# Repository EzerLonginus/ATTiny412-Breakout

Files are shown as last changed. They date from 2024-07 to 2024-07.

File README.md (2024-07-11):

# ATTiny412-Breakout
Simple breakout for the ATTiny412 using USB for uploading and serial comms

This board is a simple breakout for the ATTiny412.  This allows for programming and UART serial communications through a USB interface.  Included in breakout is a power led indication, and a few feedback LEDs for UART and UPDI programming.  UPDI and UART need to be selected via switch on the front of the breakout.

## Purpose
I wanted a way to quickly and easily test some software with the attiny412 (or similar avr chip), and not have to have a programmer and separate power source connected to chip.  This usually involved using a USB connector for power (sometimes doubling as a serial comms port) and some UPDI programmer to upload code.  This board will hopefully just allow me to use the USB for all functionality and to make development a little be cleaner and easier. 

## Scematic
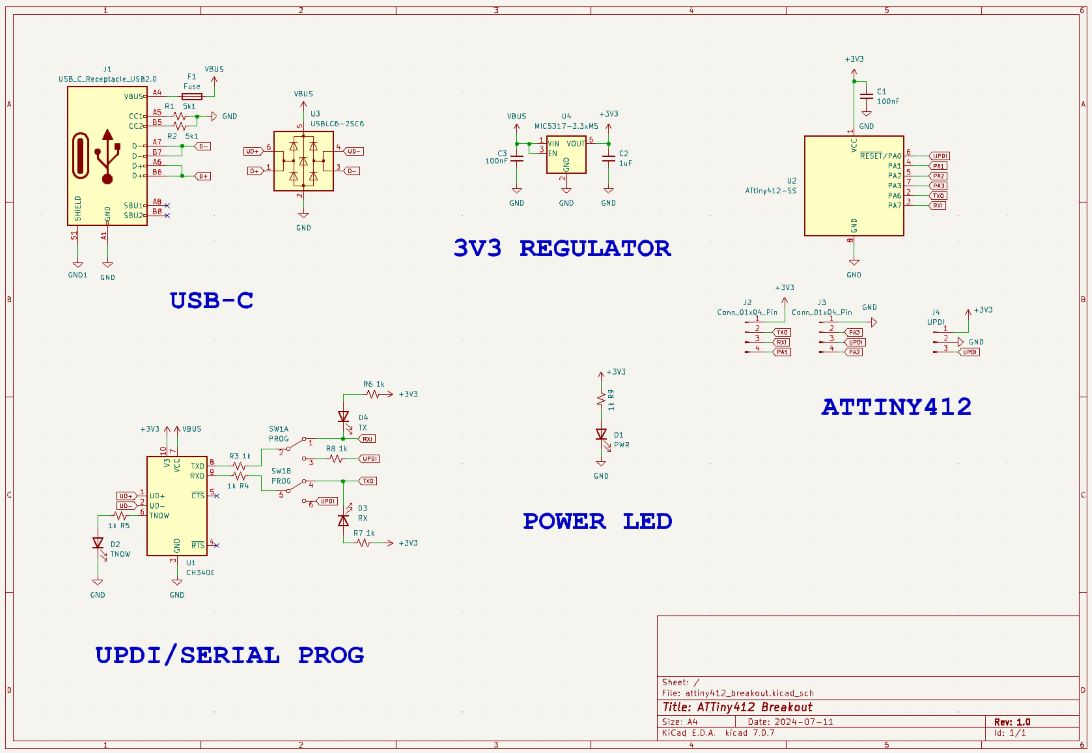
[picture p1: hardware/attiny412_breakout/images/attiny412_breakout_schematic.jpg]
ATTiny412 Schematic


## Layout
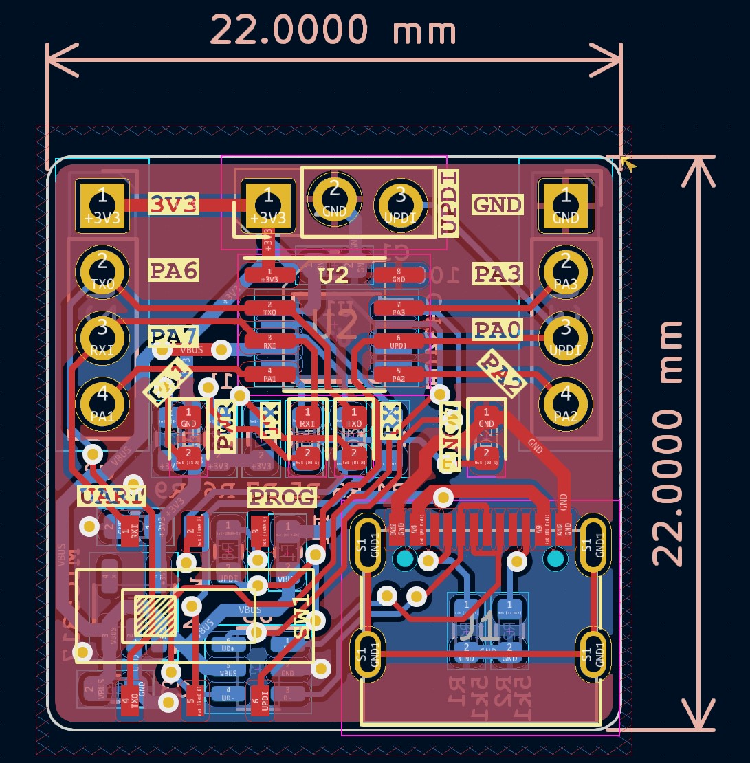
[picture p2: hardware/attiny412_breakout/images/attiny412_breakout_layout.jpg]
ATTiny412 Layout


## 3D Render
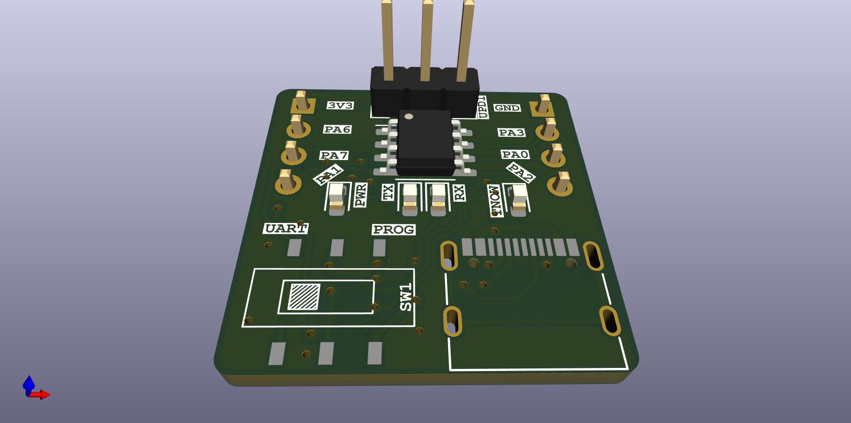
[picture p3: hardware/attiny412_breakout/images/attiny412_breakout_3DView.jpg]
ATTiny412 Render


## Current State of Affairs
### Version 1
* Populate and test board
* Fix the inevitable issue that I missed during production

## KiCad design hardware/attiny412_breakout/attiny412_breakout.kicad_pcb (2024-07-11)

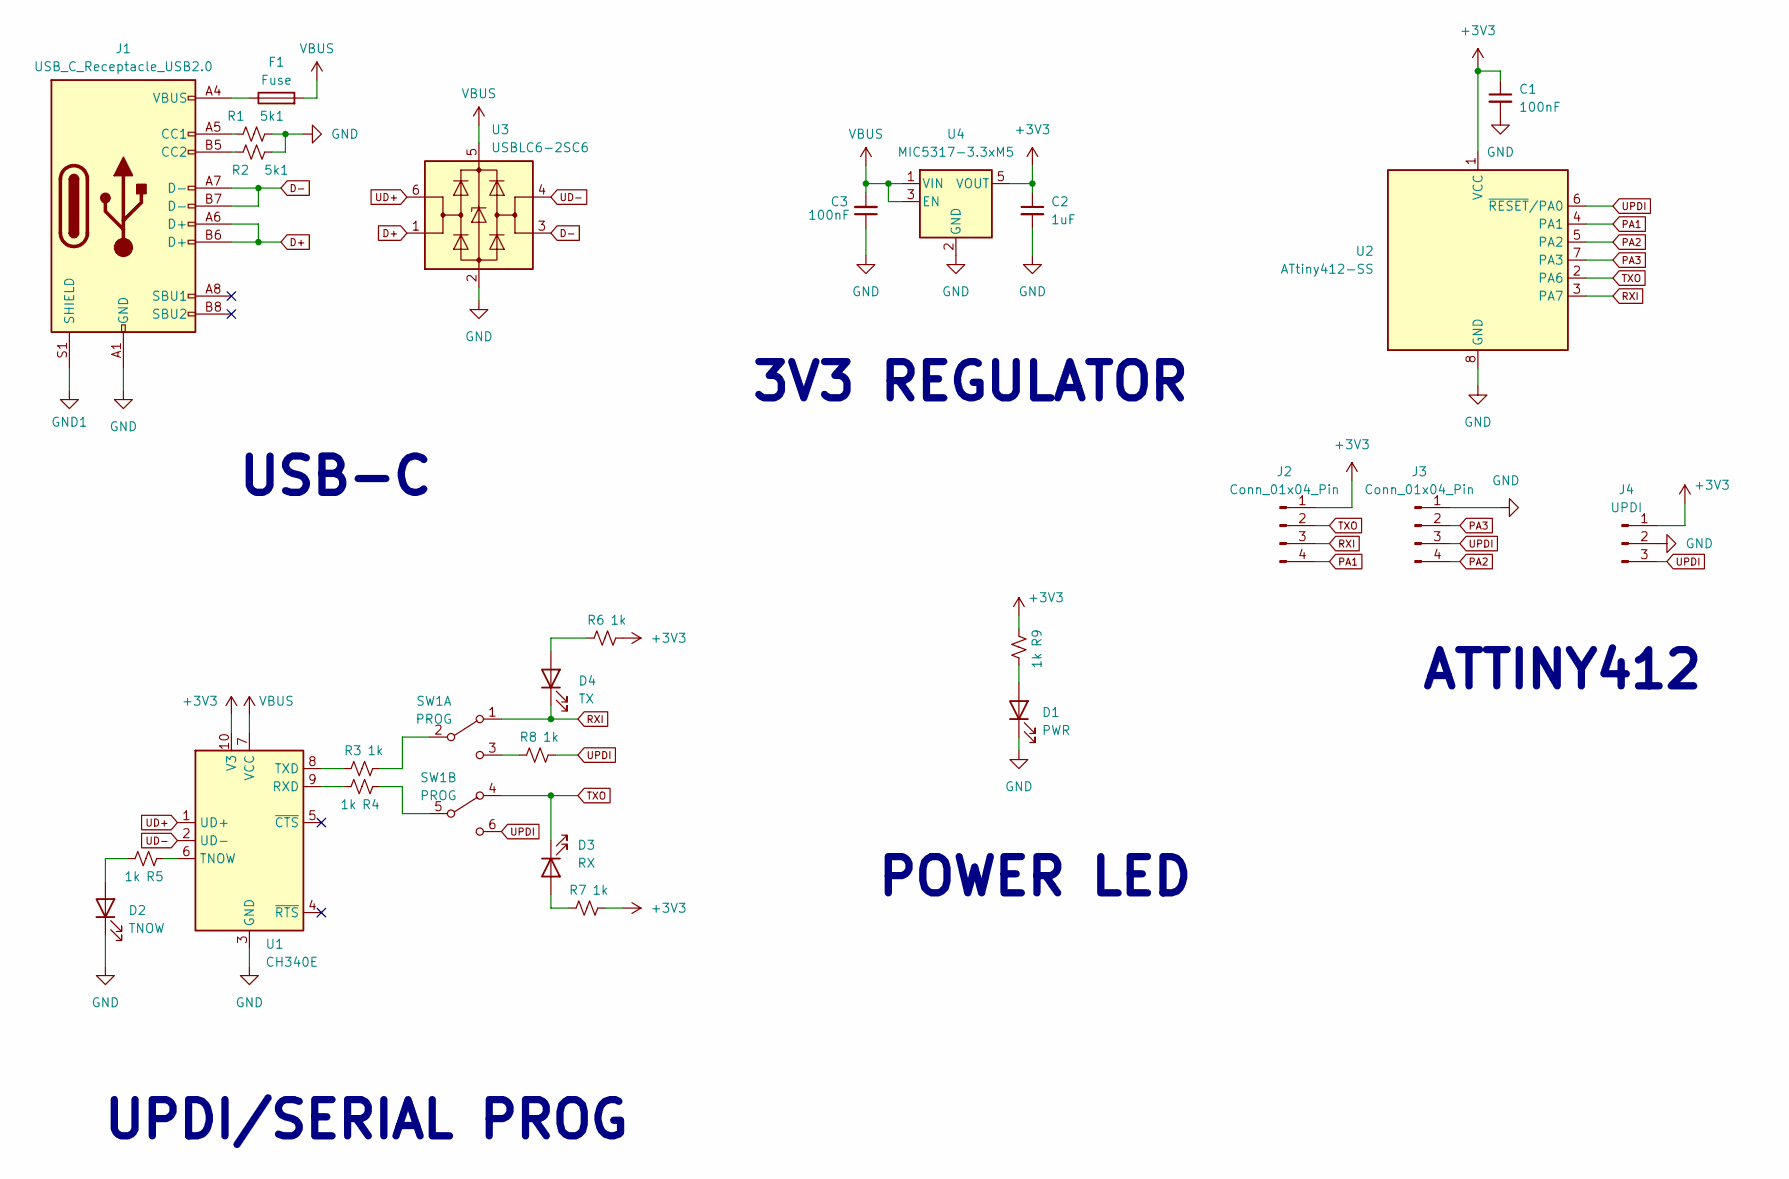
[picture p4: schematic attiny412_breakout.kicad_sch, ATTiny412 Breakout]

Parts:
C1, C3: 100nF; C_0603_1608Metric
C2: 1uF; C_0603_1608Metric
D1: PWR; LED_0603_1608Metric
D2: TNOW; LED_0603_1608Metric
D3: RX; LED_0603_1608Metric
D4: TX; LED_0603_1608Metric
F1: Fuse; Fuse_0603_1608Metric
J1: USB_C_Receptacle_USB2.0; USB_C_Receptacle_G-Switch_GT-USB-7010ASV
J2, J3: Conn_01x04_Pin; PinHeader_1x04_P2.54mm_Vertical
J4: UPDI; 1x3_2.54mm_pin_staggered
R1, R2: 5k1; R_0603_1608Metric
R3, R4, R5, R6, R7, R8, R9: 1k; R_0603_1608Metric
SW1: PROG; SMD DPDT Toggle SS-3235S-L1
U1: CH340E; MSOP-10_3x3mm_P0.5mm
U2: ATtiny412-SS; SOIC-8_3.9x4.9mm_P1.27mm
U3: USBLC6-2SC6; SOT-23-6
U4: MIC5317-3.3xM5; SOT-23-5

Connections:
+3V3: C1.1, C2.1, J2.1, J4.1, R6.2, R7.2, R9.1, U1.10 (V3), U2.1 (VCC), U4.5 (VOUT)
D+: J1.A6 (D+), J1.B6 (D+), U3.1 (I/O1)
D-: J1.A7 (D-), J1.B7 (D-), U3.3 (I/O2)
GND: C1.2, C2.2, C3.1, D1.1 (K), D2.1 (K), J1.A1 (GND), J1.A12 (GND), J1.B1 (GND), J1.B12 (GND), J3.1, J4.2, R1.2, R2.2, U1.3 (GND), U2.8 (GND), U3.2 (GND), U4.2 (GND)
GND1: J1.S1 (SHIELD)
unnamed: D1.2 (A), R9.2
unnamed: D2.2 (A), R5.2
unnamed: D3.2 (A), R7.1
unnamed: D4.2 (A), R6.1
unnamed: F1.1, J1.A4 (VBUS), J1.A9 (VBUS), J1.B4 (VBUS), J1.B9 (VBUS)
unnamed: J1.A5 (CC1), R1.1
unnamed: J1.B5 (CC2), R2.1
unnamed: R3.2, SW1.2 (B)
unnamed: R8.1, SW1.3 (C)
unnamed: R4.1, SW1.5 (B)
unnamed: R4.2, U1.9 (RXD)
unnamed: R5.1, U1.6 (TNOW)
unnamed: R3.1, U1.8 (TXD)
PA1: J2.4, U2.4 (PA1)
PA2: J3.4, U2.5 (PA2)
PA3: J3.2, U2.7 (PA3)
RXI: D4.1 (K), J2.3, SW1.1 (A), U2.3 (PA7)
TXO: D3.1 (K), J2.2, SW1.4 (A), U2.2 (PA6)
UD+: U1.1 (UD+), U3.6 (I/O1)
UD-: U1.2 (UD-), U3.4 (I/O2)
UPDI: J3.3, J4.3, R8.2, SW1.6 (C), U2.6 (~RESET/PA0)
VBUS: C3.2, F1.2, U1.7 (VCC), U3.5 (VBUS), U4.1 (VIN), U4.3 (EN)

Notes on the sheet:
ATTINY412
3V3 REGULATOR
POWER LED
USB-C
UPDI/SERIAL PROG

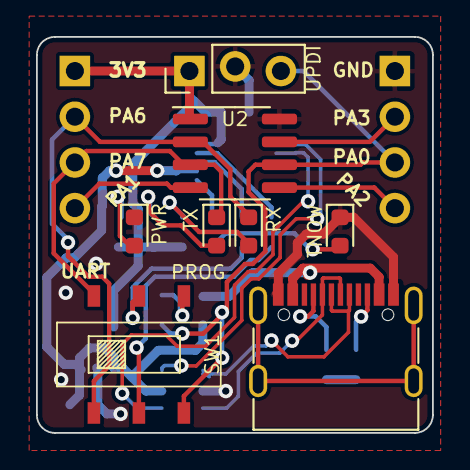
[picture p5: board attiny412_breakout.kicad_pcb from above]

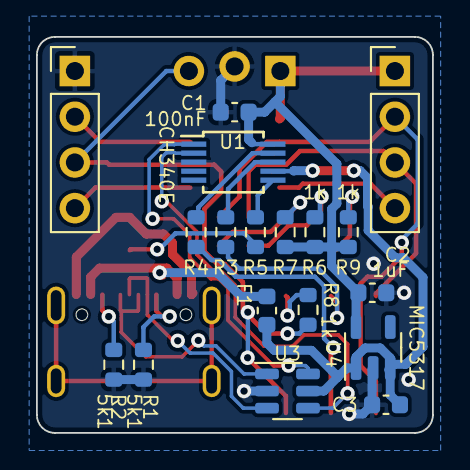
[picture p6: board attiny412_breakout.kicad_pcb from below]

Board: 2 copper layers, 22.0 x 22.0 mm, 26 parts (18 on the bottom side), 26 nets.
